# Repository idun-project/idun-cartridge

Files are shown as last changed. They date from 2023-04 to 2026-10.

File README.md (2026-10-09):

## Idun for the Commodore 128 and C64

This is the home of the idun-cartridge for the C128/64. Here you will find the latest software, along with source code, sample applications, and other content.

This innovative cartridge integrates a Raspberry Pi to provide a fast hardware interface, enabling features such as virtual disks, networking, and the ability to run modern applications. Users can interact with the cartridge via BASIC commands, a web-based file browser, or SSH, and the project supports developing new software in 6502 Assembly, Lua, and even C and Z80 Assembly. There's an optional Commodore Kernal patch that allow native software to access cartridge functionality at high speeds, effectively turning the cartridge into a "hard drive" for Commodore.

What does it do? It's easier to show in a demo, and there are many demo videos on [YouTube](https://www.youtube.com/@idunproject).

There's also a [Discord Server](https://discord.gg/qUGaUCaBEU) for the project. This is for idun-project discussion, new user advice, beta testing new features, and general retro-computing banter with a  Commodore bias.

### Hardware

The idun-cartridge uses a Propeller 1 micro-controller to provide a fast hardware interface between the Commodore and a Raspberry Pi ("RPi") that runs a customized Linux OS. The cartridge is designed to work and fit best with the Raspberry Pi Zero 2. However, any recent Raspberry Pi can be made to work.

The first set of photos show the idun-cartridge with RPi Zero 2 fitted. As you can see, a standard-sized C64/128 cartridge case can be hacked to cover the board, but leave the RPi, ports, and button accessible.

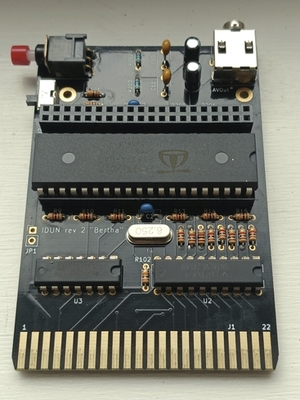
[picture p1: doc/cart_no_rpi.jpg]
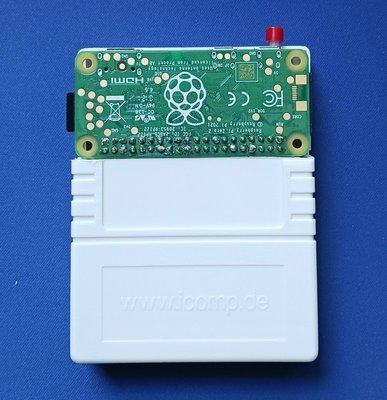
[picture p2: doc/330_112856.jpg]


 A Model B RPi will also fit on an idun-cartridge, as this photo shows. For both Model Zero and Model B, the RPi is fitted on top of the idun-cartridge and upside-down. For the Model B, a case or other support is essential because of the weight.

You can also fit a Model A RPi, but the headers must be relocated to the opposite side of both the idun-cartridge PCB and the RPi itself. In this case, the RPi will be on the bottom (under the idun-cartridge), as shown here connected to a flat C128.

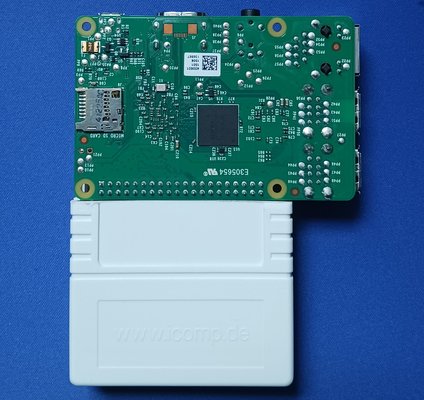
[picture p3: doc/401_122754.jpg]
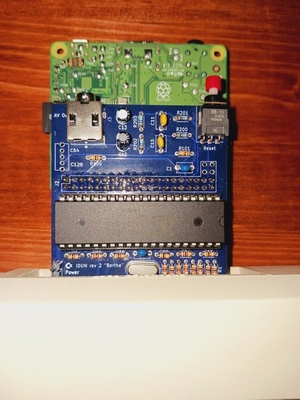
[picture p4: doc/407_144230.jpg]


### Support the project

The best way to support the project is to [buy a hardware kit](https://www.tindie.com/products/29946/) from the online store. The kit comes with everything needed to assemble the idun-cartridge, except for the Raspberry Pi, which you will need to obtain yourself. Only basic soldering skills are needed, since the PCB is strictly through-hole components.

### Quick start

#### Download SD Image

You can download the customized Arch Linux OS image and flash it to a microSD card.

1. Ensure you have a suitable SD card compatible with your Raspberry Pi and at least 4GB (recommend 16 GB).
2. [Download Image](https://drive.google.com/file/d/1j5v-0p9-eopSoVMuX6h2P_U8w21OJF-Q/view?usp=drive_link)
3. Use [Raspberry Pi Imager](https://www.raspberrypi.com/software/) or a similar program to write image to SD card.
4. **IMPORTANT** If you have received an idun-cartridge with a _unique serial number printed on your instruction sheet_, then you need to transfer that serial number onto your SD card. This is essential for your cartridge to work properly. Using a text file editor, modify the file "idunhw.toml" located on the first partition of the SD card. This is the "boot" partition and it is in the FAT32 disk format, which should easily mount on the same computer you used to write the image. Open the "idunhw.toml" file and set the serial number you received in the `hw.serial` line of the file, then save it back to the boot partition.

If you are going to use idun-cartridge on a C64 Ultimate, then you need to install the Ultimate configuration file before trying to use the cartridge. You can grab the file [here](https://raw.githubusercontent.com/idun-project/idun-defaults/refs/heads/main/Idun_c64u_run_first.cfg) and transfer it to your Ultimate by any available means (i.e. network, USB). Then, *run that config file* from the Ultimate menu and *save the new configuration* to Ultimate's Flash.

Your microSD is now ready to use with your idun-cartridge. To expand the file system or setup networking, follow the additional instructions in [setup-rpi.md](https://idun-project.github.io/docs/doc/setup-rpi/).

#### Power

It is recommended that you power the RPi externally from a USB power supply. The jumper (JP1) that allows power to come from the Commodore is not installed by default, and only suited for the RPi Zero 2. Even then, it makes it too easy to turn off the Commodore and Raspberry Pi without first shutting it down via the button. Plus, it is nice to be able to access the cartridge using the web filebrowser, emulation, or `ssh` while the Commodore is switched off.

#### Cartridge Mode & Reset

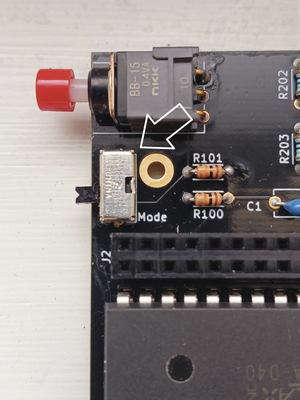
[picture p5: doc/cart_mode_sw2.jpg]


The idun-cartridge has a single "big red button" with dual use. Press and release immediately to Reset everything, including rebooting your Commodore. Press and hold for at least 5 seconds to shutdown your cartridge, which is necessary before powering it down. If you power your cartridge from an external USB power supply, as is recommended, then you will rarely need to perform any shutdown. The cartridge can run for months without requiring any reboot or power-cycle.

As of release v1.2.0, the idun-cartridge has two different modes, controlled by the setting of the Mode toggle switch. When the switch is "Off" (switch position farther from exp. port), the idun-cartridge works on the C128 in its native mode. However, when switched to "Mode", a different software stack is selected as specified by the settings in the configuration file.

With the default configuration file, setting the switch to the "Mode" position enables C64 support. This means that the cartridge can be used on a C64 and that it will boot a C128 into its C64 mode. If you are primarily wanting to play C64 games, then you can most easily do so by launching the arcade.app using the command `go "arcade"`.

#### BASIC commands and launching Apps

When you reset the cartridge by pressing the red button, it starts the Linux shell by default. If you hold down the Commodore key on the C64, then it starts a customized BASIC with some utilities for accessing the Idun virtual disks. The screen lets you use the cursor keys to select which virtual drive to use and on which IEC address; the normal default is `C:`, which is the HOME directory, on IEC device 10. Once you hit "RETURN", you will be in Commodore BASIC.

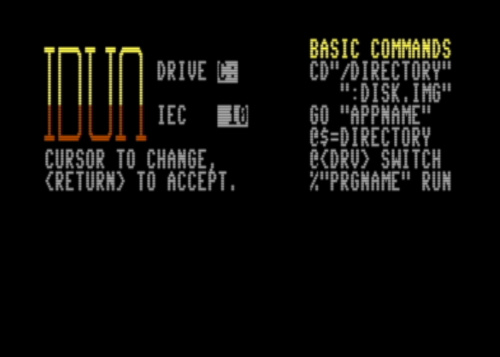
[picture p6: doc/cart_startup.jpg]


From the BASIC prompt, you can use any of the several commands that are briefly described in the boot screen. Mainly, you can navigate the virtual disk by using `@$` (also `F3` on the C128) to load directories, and the `cd` command to change directories. Any disk image file can be mounted by using `cd` and prefixing the image file name with a ":". This will switch you automatically to the `D:` device, which is where the disk is mounted. You can switch back to the `C:` device using the command `@c`, and switch to any other virtual disk this way. If you want to load and run a program, just locate it in the directory, place a `%` in column 1, and "RETURN". This is equivalent to typing `% "prgname"` on a new line.

The other thing you can do is launch an Idun Application. This is done with the `go` command, and entering just that will quickly launch the default shell. The default shell is controlled by the configuration file, and is normally setup to load `dos.app`, which is the idun-shell and an MS-DOS work-a-like. Other applications, such as the Arcade Selector for running games can be started similarly, using `go "arcade"`. Any app on the cartridge can be started this way, and you can create your own using programming tools that run right on the cartridge!

#### Networking and Managing Files

It's well worth connecting your cartridge to your LAN. Convenient file management can be done through the web-based idun-filebrowser at `http://idunpi.local`; it even includes remote file editing and drag&drop. Using the provided `share` command from Linux, you can also enable the cartridge to serve files to your network using both WebDAV and Windows file sharing. Linux terminal access is also there using an `ssh` client from any computer. Then there are also networked applications that allow you to [stream SID tunes](https://youtu.be/EPf45QN3PJk) or [share huge game libraries](https://youtu.be/NZajjJ2tERM) from a Windows computer.

#### Emulating the Cartridge

You can also run [idun-vice](https://github.com/idun-project/idun-vice) to experiment with the idun-cartridge software WITHOUT any actual cartridge; just running everything off of the Raspberry Pi. The emulator is not installed by default, but is easily added with the `apk` packaage management command. It runs Idun software just like on the cartridge and is an excellent way for developers to debug new tools and applications they develop with Idun.

### Configuration

Configuration options are available in `$HOME/.config/idunrc.toml`. There is documentation within that file, but the following hints are also helpful.

1. Because of the "special" VDC hi-res graphic modes used by some of the software (e.g. `showvdc`), it is very important to set the correct amount of VRAM in the configuration file to either 16kB or 64kB, as appropriate. The setting is the second parameter in the `[vdc]` section.
2. Some monitors are picky about how many rows of text they can display in 80 column mode, and how they look when displaying text in interlaced mode. The default is 27 rows, non-interlaced. You can modify this by changing the first parameter in the `[vdc]` section, and for interlaced text, the section `[vdc_interlace]`. Also take a look at the `mode` command for changing the number of text rows on demand (not to be confused with the mode switch described above).
3. If you are using idun-vice to connect to your cartridge from a remote Windows computer, pay attention to enable remote connections by modifying the `io.socket` setting; otherwise, Idun will refuse to talk to remote computers.

### Building Commodore code

The idun-cartridge software in this repository is self-hosting. All of the assembly code is built with the `acme` cross-assembler and everything you need to build and modify it can be done on the cartridge itself. You can perform each of these steps from the Linux prompt:

1. Clone this repository to your idun home directory: `git clone https://github.com/idun-project/idun-cartridge`
2. `cd idun-cartridge && ./setup.sh` -installs additional packages such as bastxt and idun-zcc
3. `cd cbm && make` -builds cartridge software
4. To make the new cartridge software active, just `sudo make install` from the `cbm` directory.

See the [Makefile](https://github.com/idun-project/idun-cartridge/blob/main/cbm/Makefile) for details.

### Patched Commodore Kernal (Optional)

The latest ROM kernal patch can be created easily with idun v1.1.9 and above using the command `mlua makerom.lua` from within the Idun Shell. The patched ROM file(s) will be found in your home directory on the cartridge, and most easily copied using the web file browser or a network command like scp. By default, this creates a two 16kB kernal replacement ROMs for the C128 (U32/U35).
1. To make the 8kB C64 replacement ROM (U4), use `mlua makerom.lua /8`
2. To make the 32kB C128D replacement ROM (U32), use `mlua makerom.lua /32`

The patches to the C128 kernal overwrite the kernal's support for RS-232 devices. This code is frequently unused by native software anyway. If you also update the C64 kernal (U32), then you lose both RS-232 and cassette tape support in C64 mode.

With the kernal patches in place, things work pretty much the same, except that you can access cartridge functionality easily through standard Commodore ROM kernal routines, rather than loading Idun's own kernel into RAM. So, in theory, native Commodore software that is programmed to use kernal routines for file access can "transparently" access files via the cartridge and at "breakneck speed". Think of it as basically a hard drive for the Commodore without having to go through the Idun software drivers in RAM. So now those drivers can just be overwritten by some program.

You really only need to know about two zero-page variables to control the ROM patch - $9b/$9c (155/156). So you can POKE 155, 10, for example, to setup the cartridge as IEC device #10. And, you can POKE 156, 3 to setup the cartridge to use idun's C: device, which is default configured to the Linux home directory. Using other values let's you easily switch to any Idun device mapped as any IEC device. This opens up the cartridge to native software that can use it for virtually anything without requiring RAM drivers. By the way, setting values in $9b/$9c is just what the little booter program the cartridge starts up with does - When you use the cursor keys to modify the IEC and Idun device selection, you are changing these two memory locations. 

### Programming applications

The idun-cartridge works with many legacy applications. Single-file loaders in particular work very well and load instantly in either C128 or C64 mode. But the point is to enhance both the user and programmer experience with applications that integrate into the idun-cartridge. There are currently 3 well-supported ways to create software for the idun-cartridge.

#### 6502 Assembly

Idun includes acme 6502 cross-assembler, which can be used to build both the contents of this repo and your own programs on the idun-cartridge. You should first decide whether to build a Tool or an App.

1. Tools load from the idun-shell using $6D00-$BFFF, have access to the [kernel api](https://idun-project.github.io/docs/doc/apiref/) and the [toolbox](https://idun-project.github.io/docs/doc/toolbox/), and return the user to the idun-shell on exit. They are typically command-line style programs with arguments, but can also take over the screen and run interactively. Many examples can be found in the [cmd](https://github.com/idun-project/idun-cartridge/cbm/cmd/) sub-directory
2. An App is launched by the kernel at startup using $6000-$BFFF, has access to the kernel API, but not the toolbox _unless_ `sys/toolbox.asm` is explicitly included, and return to BASIC, or not at all. They typically take over the machine and reconfigure the hardware as needed. Examples are `shell.app` (the Linux shell) and `arcade.app` (the arcade game selector).

It is certainly possible to use other assemblers besides acme; just requiring that the header files `acehead.asm` and `toolhead.asm` be ported over to your environment.

#### Lua Scripting

The idun software running on the Raspberry Pi embeds a Lua scripting engine. This allows you to create either Tools or Apps in which much, even a majority of the functionality, is implemented in Lua.

Begin by reading [luaref.md](https://idun-project.github.io/docs/doc/luaref/). There is sample Lua App code in [samples](https://github.com/idun-project/idun-cartridge/tree/main/samples), and the [arcade.app](https://github.com/idun-project/idun-cartridge/blon/main/cbm/arcade.app.d/main.lua) is Lua. These can serve as a template for creating your own Lua App.

 _NOTE: There is a forthcoming tool called `mace` that will generate new Lua Apps automatically, including all the boiler-plate needed._

#### C and Z80 Assembly 

You can create programs that run on the Z80! They launch seamlessly from the idun shell, and return to it on exit. These are more akin to Apps than Tools, except for their use of the `zload` command and launching from the idun shell. The programs can be written in both C and Z80asm code, and can be built directly on the idun-cartridge. For more information, browse to the [idun-zcc](https://github.com/idun-project/idun-zcc) repository.

### Trivia

[Idun](https://en.wikipedia.org/wiki/I%C3%B0unn) is the [Norse goddess](https://youtu.be/0IIcDB3noxE?t=308) of youth and [rejuvenation](https://youtu.be/GiXNEf_NOak).

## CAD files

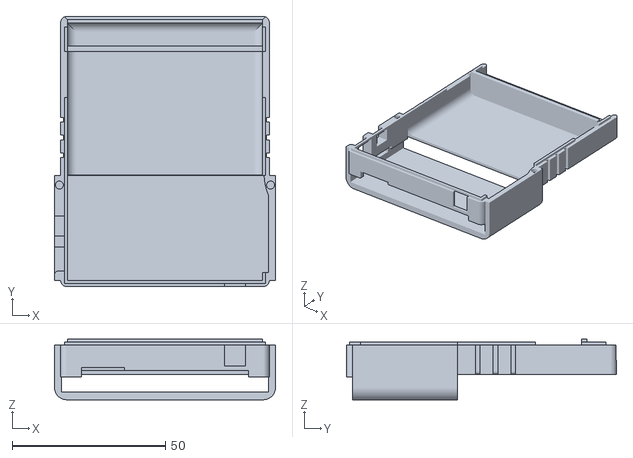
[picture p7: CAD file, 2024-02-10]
hardware/3d-printed-case/case_top.stl
72.0 x 88.0 x 19.7

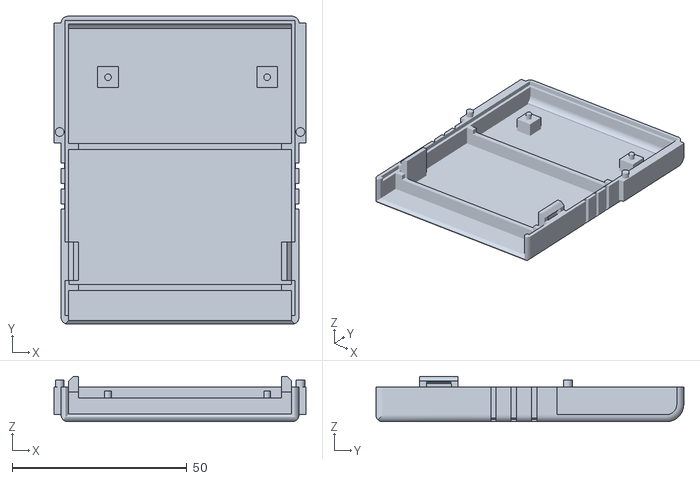
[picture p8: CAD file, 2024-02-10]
hardware/3d-printed-case/case_bottom.stl
72.0 x 87.9 x 13.0

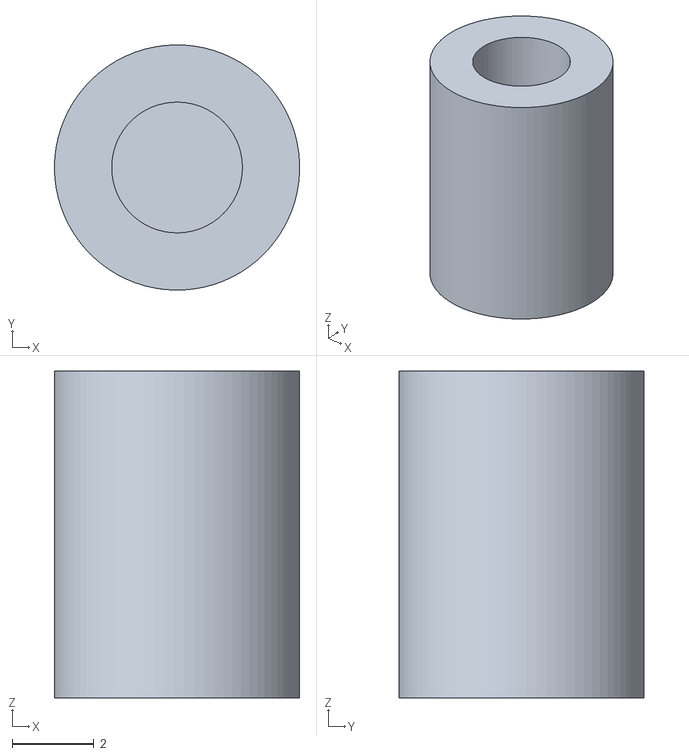
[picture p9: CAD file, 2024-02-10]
hardware/3d-printed-case/reset_button.stl
6.00 x 6.00 x 8.00

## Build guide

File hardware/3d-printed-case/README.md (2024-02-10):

This case design is suitable for 3D printers and was generously contributed by one of our users. This design  is [Licensed under Creative Commons](LICENSE).

There are two main pieces which can be press-fit together; so no screws are required. There's also a replacement button cap that makes the reset button easier to press with the case installed.

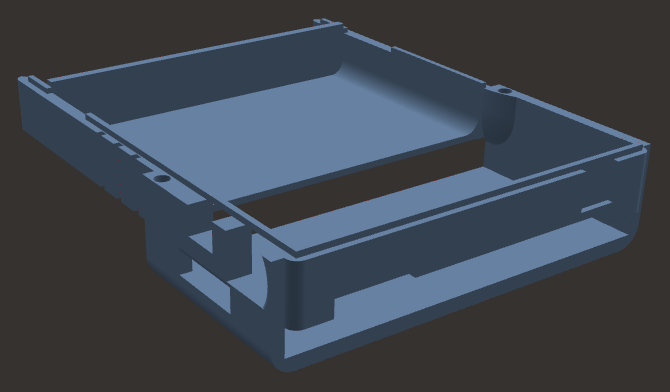
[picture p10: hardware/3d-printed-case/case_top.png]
case top


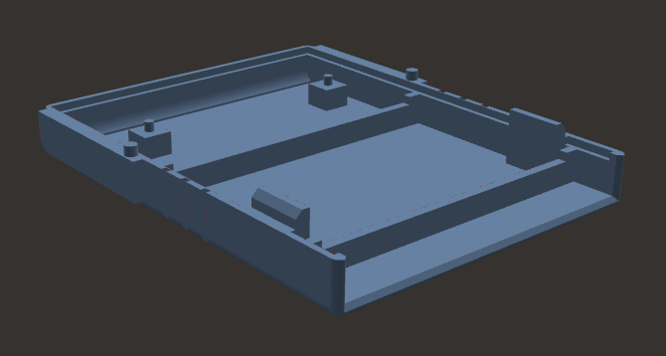
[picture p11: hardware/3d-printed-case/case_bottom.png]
case bottom


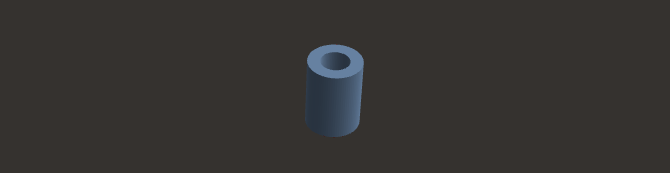
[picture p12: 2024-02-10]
hardware/3d-printed-case/reset_button.png

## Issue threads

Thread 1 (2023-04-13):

Feature Request: configurable shell

paulhocker, 2023-04-13:
First, please don't feel bad about this. I was both excited and sad to see this project. As this is something I was hoping to do for a long time.

I started a project last year called Animal Shell (https://gitlab.com/retro-coder/commodore/animal-shell) which was supposed to be a replacement for the standard command line interface for C128 using ACE, CSDOS and others as inspiration. But nothing as complicated as a operating system. I have actually made some pretty good progress, at least I think so.

You have taken this idea to the next level by incorporating the PI which is also something I had hoped to do so that one day I could use python to run programs on the C64 using the RPI as the interface.

In all, I am very excited to try this out and give my feedback and maybe one day contribute.

I saw by looking at the source code that you have some inspiration from ACE as well. IMHO it would have been great if it had continued.

At any rate, I am mostly here to say that I want to help.

Out of curiosity, how long have you been working on this and have you shared it before? I have seen nothing on this before.

Will be ordering the hardware kit soon.

Paul

idun-project, 2023-04-13:
Hi Paul.

Firstly, thank you for the kind words and support. I also understand the mixed emotions, as I've had similar experiences myself.  This project started in 2020. It was "baking" for quite a while, and even paused most of last year. For better or worse, it is not in my nature to release a project until at least I find it sufficiently useful and complete (like something worthy of calling "v1.0").

I am thrilled that you are thinking about contributing. ACE-128 is largely preserved in the idun kernel - please see [apiref.md](https://github.com/idun-project/idun-cartridge/blob/main/doc/apiref.md). The whole system is easily extended with additional shell "tools" (a.k.a external commands). And, there's certainly room for alternative shells, too.

I wonder if you mind that I'd like to retain this "Issue" as a Feature Request, with your permission. Right now, the shell ("dos.app" is the name of the binary) is hard-coded. It should probably be a configuration variable easily changeable by the user - that way typing "dos" at the BASIC prompt drops you into the shell of your choice. With that option, plus the addition of external commands, the shell can take on differing "personalities", rather than only the MS-DOS inspired "dos.app".

If you agree, let's rename this as "Feature Request: configurable shell".

paulhocker, 2023-04-13:
Of course. Please change the title.

The history of our projects is very similar. I started experimenting in 2020 as well.

I am glad you have decided to share this now, and I can't wait to try it out.

Am I right in saying there are not yet any binary distributions? You need to build everything yourself?

Not a problem, really, just wanted to be sure.

Your work on the VICE emulator is also particularly interesting as not many hardware projects consider it. Great idea.

idun-project, 2023-04-13:
There is a link in the README (see "Quick Start") for downloading an image to copy to microSD and insert into a Raspberry Pi. It has everything needed to run the cartridge.

idun-project, 2023-08-04:
Release v1.1.0 has a configurable shell app for both normal and alternate modes.

Closed 2023-08-04.

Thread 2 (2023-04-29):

Recommended 3D cartridge design

CraigBladow, 2023-04-29:
Thanks for the project.  I've done Propeller based projects and it is a fascinating hardware architecture.  I have the hardware kit and it is progressing towards completion. Can you recommended  or reference the cartridge design you used for 3D printing?

Thanks,
Craig

idun-project, 2023-04-29:
Hi Craig. My own case hacks thus far have been crude, and have not relied on any 3D printing or CAD files. I start with a standard ROM cartridge case, remove what is in the way using a small saw and file, and glue the pieces together. This has been effective for one-offs, but the project _obviously_ would benefit from a better, custom case design.

I'll keep this issue open for further discussion.

Barkfin, 2023-08-27:
This is a magnificent project! Hey I can do a 3d-printed cartridge design, no problem.
I just need some geometry info of the bare board & can whip that together easily.

idun-project, 2023-08-27:
@Barkfin That's great! I'd love to see some better case options become available.

The main PCB is standard C128 cartridge size at 84x57mm. But then the top 28mm is overlapped by a Raspberry Pi Zero 2 that is sandwiched to the main PCB and is just slightly wider. On the pictures you see in the README. you can see I just leave the top portion exposed so that all the ports on the Pi are accessible. Of course, a custom case could have cutouts for ports, and the button and switch on the main PCB. This would nicely enclose everything, but obviously would only accommodate the Pi Zero, and not the larger Model B Pi's, for example. The "open top" version has the benefit of working with more Pi's.

Anyway, I think the summary is that it needs to be a case that fits the Raspberry Pi the user intends to use (RPi Zero 2 is "recommended"), but has an "extension" of 55x57mm for the bottom part of the main PCB, and the proper height dimension to fit in the Commodore cartridge slot opening.

Barkfin, 2023-08-27:
Yes, as I figured, somebody already did this:
https://grabcad.com/library/c64-cartridge-case-1

Anyway this project is completely accessible, have a look at some of the geometry details.
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

idun-project, 2023-08-27:
@Barkfin Yes, that is indeed the "standard" Commodore cartridge dimensions. It will fit the idun-cartridge WITHOUT the Raspberry Pi, as long as the center screw post is removed - there is no hole in the idun-cartridge PCB to accommodate that. So, the necessary modification is hacking off 29mm from the top and (if desired) reforming that area to fit over the Pi nicely.

Barkfin, 2023-08-28:
Whoops, I just realized I had the Pi-2 upside down 😄

So the Pi-2 is actually 30mm x 65mm wide (at least according to the geometrical model I found).
The cartridge model extends 2.45mm past the end of the board, so that implies a 32.5mm cut top the top case.
The Pi-2 standoffs are what, about 8mm tall?

If I just do a simple trim to the top case (plus eliminate the center post) then we get this:
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
(Anybody who cares to try, here are the STEP-214 files)
[Idun cartridge case.zip](https://github.com/idun-project/idun-cartridge/files/12450316/Idun.cartridge.case.zip)

idun-project, 2024-02-10:
There's a new and improved 3D case design, generously contributed to the project by @_.cygnus._ . If you want a case, then checkout the design files in the GitHub repo:

https://github.com/idun-project/idun-cartridge/tree/main/hardware/3d-printed-case

Closed 2024-02-10.

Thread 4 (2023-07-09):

Boot issues on Neo128 board with Saruman SRAM

insanity213, 2023-07-09:
The RasPi boots to arch (watching via HDMI) but I crash to the monitor when the Neo128 fires up. On initial boot it always dumps at A803B with processor state SR:31 AC:04 XR:03 YR:00 SP:F5. If I reset with the Idun’s cart button it’ll crash to the monitor at seemingly random vectors or sometimes just hangs. Disassembling memory in these areas doesn’t seem to yield anything significant, seems to just be random junk in there but admittedly I’m not the brighest when it comes to 6502 assembly. The only noteworthy difference I can think of is that I’m using the Saruman SRAM module on this Neo build.

Some things I’ve tried so far:
Powering the PiZero2 either internally or externally
Wrote a new micro SD card with the latest image
Tried the original CBM kernal and JiffyDOS
40 or 80 column mode
Reflowed IC solder joints
Retested on original C128 board with DRAM and the cart functions perfectly

I did successfully boot one time but as soon as I issued the DOS command it crashed to the monitor.
I’m starting to wonder if this could possibly be a RAM timing issue with the static ram replacement module I’m using instead of DRAM? I was wondering if you’ve used this cart with a SRAM replacement or ran into any tight timing issues when developing the cart.

Monitor output of A8007 and A8017 looks correct.

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

idun-project, 2023-07-09:
From the monitor, it would also be useful to see the contents of $C1:
M C1 -> should be "00 13".

If that is Ok, then the next thing to look at is the disassembly at $1300.
D 1300 -> first instruction should be JMP $1305, followed by lots of valid 6502 code starting from $1305.

If this is no good, then the issue is on the I/O side, for sure, and not on the ROM side, of the cartridge functionality. Naturally, the timing is critical for reading the I/O at the cartridge port. It's not yet registering with me how the SRAM mod could effect the bus timing when reading from external I/O at $DE00. It would have to be effecting something fundamental with the C128 Phi2 clock OR with the "clock stretching" that it does when running in 2MHz mode.

insanity213, 2023-07-10:
I tried 40 column mode.  It seems the Idun is more likely to boot on a cold start in 40 column mode but crashes within a few minutes.  I was actually able to enter DOS then hit F7 to get to the Linux shell on one occassion.

After crashing back to the monitor I looked at the output of $C1 and $1300.  C1 was 00 00.  $1300 looks different each time I've rebooted/crashed/dumped the RAM in the monitor.  Also had one crash where it just hung on a garbled screen.
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

Anecdotal / mostly unrelated - In the past on the C64 I had problems with combinations of SRAM/Cartridge/Kawari VIC-II that I was able to work around by 'tuning' PHI2 a bit.  I disconnected PHI2's output from the CPU and generated my own PHI2 through a pair of inverter gates on an LS14 and manipulated it a bit with a low value capacitor in order to get the system stable.   I didn't have any of these problems in machines with DRAM.  The Kawari developer also made some tweaks to RAM timing to get his device to work with SRAM but I'm not 100% sure exactly what he did.  I think it had something to do with RAS/CAS.

I know the 8502 in the 128 doesn't generate the PHI2 and I'm comparing apples to hand grenades but I though it was worth mentioning.  I'm wondering if CAS or RAS falls at a different rate when attached to an SRAM module and it nudges the timings off the mark just a hair, similar to the Kawari issue. Playing with the edge of PHI2 may help those timings hit the mark?  All guesses on my part really...  I wish I had a logic analyzer to dig in deeper, but I only have a cheap 2 channel scope.

idun-project, 2023-07-10:
The plot thickens. If the system goes from crashing immediately, to working but unreliabe, just by switching to 40 column / 1 MHz mode, then it makes sense to assume that Phi2 pulses are affected by the SRAM. And that is causing the cartridge IO to fail outright in 2 MHz mode and to become unreliable in 1 MHz mode.

Anything 100% reproducible that leads to a crash in 40 column mode could help localize the problem. I think 80 column mode will remain "hopelessly" broken until the root cause is better diagnosed. Any O-scope output of Phi2 at the cartridge port on a DRAM vs. SRAM C128 would also be useful.

I have to say the timing tolerances are quite tight already. If the Phi2 edge pulses are coming quicker than normal, we can't just patch the cartridge software to allow for that - spare cycles aren't available here and the Phi2 clock is what is used to "trigger stuff" in the code.

insanity213, 2023-07-18:
Problem resolved, it was related to the 1mhz clock line between the VIC-IIe and the cartridge port.  Also noteworthy was that with DRAM installed the system was marginally more stable but still had issues.  At least I was able to boot into the Idun DOS shell and run a demo or two before it would crash.  With SRAM I was lucky to get it to boot at all.  My issue seems to stem from the amplitude of the 1 mhz clock generated by this particular VIC.  I swapped it out for a spare and the system started running perfectly.  I guess some VICs have stronger clock signals than others.  See attached scope pics.

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

insanity213, 2023-07-21:
Yeah, kind of a weird one.  I guess having just a tiny bit less amplitude on that signal was enough to make the falling edge too short for stuff to time right.  I had some odd behavior with the Ultimate II cart as well with that weak VIC in there.

I did try putting a 330 in parallel with the 1k on that line and it didn’t make a difference.  I didn’t want to go too much lower and let the smoke out of the Propeller though.  Thanks for your help, I really appreciate it!

Ray

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

idun-project, 2023-08-14:
@insanity213 I was wrong in my initial assumption that the read response time for the cartridge couldn't be improved (Propeller multi-core for the win...)

In light of the resolution to #5 , it might be worth testing again with your original VIC-IIe chip.

insanity213, 2023-08-15:
I reflashed my SD card from scratch with 1.1.1 and reinstalled my 'weak' VIC-IIe.  Your fix certainly improved the situation but the machine is still quirky with this VIC and the Idun cart.  I ran the cube app for about 15 minutes then started to see corruption in the video.  Upon exiting the cube app and going back to the shell I got some strange behavior with screen updates and cursor movements but the machine didn't full out crash like it used to.  I tried to reset with the button but struggled to get back to the shell.  Also, there may be another unrelated bug at play where for some reason 1.1.1 is ignoring the VDC config in idunrc.toml.  I'll open a separate issue for that.

Closed 2023-07-18.

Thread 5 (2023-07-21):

IDUN Not Loading on C128D(CR)

kd4cbm, 2023-07-21:
It appears as though I either have an issue somewhere or the internal drive may be causing issues with IDUN loading on a C128DCR.

RPi software wise, the OS and everything else on the SD card is bone stock with zero modifications with the exception of installing the Vice package.

Has anyone had a successful load on that specific 128 type? RPi Vice appears to be working locally, albeit a bit slow.

The cart does hold up the c128 boot process until the Pi completes loading so I assume the correct lines are toggling.
I did do another SD card where I incremented the device ID's by 1 in the config file. The result was the same though.

I have a 128 flat I might be able to test with, I'll just have to figure out where I hid its power supply.

idun-project, 2023-07-21:
Hi. Much of the idun-cartridge testing was done on a 128D. I don't have a working 128D(CR) to test with right now, but can't foresee why there would be any issue. Internal floppy (is it set to IEC device #8 or #9?) should not effect boot process.

Are your symptoms anything like those reported in issue #4 ?

kd4cbm, 2023-07-21:
I've had very, very, few break conditions. What I'm seeing is either the machine boots to a ready prompt or just hangs at the Commodore copyright notice that shows just before ready does.

I've looked at issue #4 and plan on probing around with the scope over the weekend to see what I can find.

The internal drive is still set to 8. If it works on a D, I would imagine the CR variant should work as well.

I'll post back here once I start probing around and have some useful info to share.

Thanks!

kd4cbm, 2023-08-01:
Sorry for the delay on the follow up. I wanted to rule out any hardware issues before I started probing and USPS is getting slower and slower these days.

I believe I am in fact seeing the same issue as described in issue #4, they are just presenting themselves a little differently. Differently as in the 128s are either hanging while attempting to load the cartridge data into memory, or just booting normally with no code loaded. The behavior is the same between the machines.

On the scope, there is a pretty good amount of slew and noise on the clock line which may explain why the user who reported #4 got better results with a stronger VIC. That extra .4v may have been enough to get the timings in check. I tried dropping the clock line resistor down slightly to 800ohms with no improvement. I'm a little cautious on going too low, since I've already smoked one Propeller due to my ham-fisted Pi alignment.

I did try the VIC from my flat 128, but the results are the same regardless of the VIC, or which machine it's in. I'm not terribly surprised by this though since both VICs were manufactured within 2 weeks of each other, and their clock outputs are nearly identical to each other in terms of output. If I can get my hands on an expansion port breakout, I'd like to try intercepting the clock output at the port and buffering it with another 74LVC245 or similar directly to the MCU pin to see if it solves anything.  Or even just jumpering from a point somewhere close to the VIC directly to the input resistor on the cart...

idun-project, 2023-08-01:
Hi. So if you have a chance later, would you please provide the date codes on the two VIC-IIe chips you have? I'd like to compare with those in my test machines, and also find a VIC-IIe of my own with which I can reproduce the problem.

kd4cbm, 2023-08-01:
4585 and 4385 are the date codes on the 2 VIC-II's I've got in hand. I'd be happy to loan you my spare if it would be helpful, especially if it leads to a solution. My C128 use case makes this particular cartridge perfect for my needs once I get things up and running.

I would prefer to facilitate that communication via e-mail if you're interested. Google's e-mail service, same username

idun-project, 2023-08-14:
Thanks to @kd4cbm for lending me one of his R5 VIC-IIe's. The following was learned:
1. The 8564R5 is unreliable with the idun-cart.
2.  Phi2 as detected at the Propeller input is identical for R5 and R6. It does not appear to be a clock problem.
3. The difference is thermal. My flat C128 booted Idun perfectly the first time with the R5 chip, and anytime that I allowed the C128 to cool completely back to ambient temperature. It becomes unstable after a short warm up time, which affects the timing tolerance for reading from the cartridge port.

Release v1.1.1 shaves 80ns of response time for cartridge reads. This is enough for it to work reliably with the R5 chip.

Closed 2023-08-14.

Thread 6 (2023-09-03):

Out of sync 80 column mode

celso, 2023-09-03:
Hi,

First of all congrats on the idun cartridge project, I just finished soldering mine, had it running in my C128DCR and it's mindblowing. Thank you.

I'm having problems running DOS in 80-column VDC mode with my C+1084S monitor (connected with the std analog RGB cable).

It boots fine at first, shows the IDUN banner, but as soon as I type and run DOS the video gets out of sync. See attached screenshots.

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

I can see DOS is running properly though, I can even type commands and it's fine, just doesn't show stabilized video.

I looked into idunrc.toml for options. And found:

```
[vdc]
offset = 169
config = [27, 16]       # VDC default lines, memory size in KB
```

Changed it ,64 since afaik the DCR has 64K VRAM, but it didn't help.

Any clues on what might be happening and how to fix it?

celso, 2023-09-03:
I did try setting an interlaced mode and got good video:

```
mode vdc 0 80 47
```

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

Still, I tried a bunch of non-interlaced modes changing the number of lines from 20-27, and they were all out-of-sync.

celso, 2023-09-03:
On a separate note idun doesn't seem to be picking the `/home/idun/.config/idunrc.toml configuration` at all. I changed a few settings, then resetted the cartridge, even rebooted the raspberry pi, just in case, and nothing.

Is this the correct path? Do you want me to create a new issue for this?

idun-project, 2023-09-03:
Hi. I would suspect that the monitor was having trouble syncing with the default 27-line non-interlaced text display. Changing the default lines to 24 in the configuration file should work. But typing "mode vdc 0 80 24" at the C: prompt should also work.

On my CRT I can set the number of lines up to 29 non-interlaced and 50 in interlaced mode without sync issues- just at very high line counts it does start to disappear off the top and bottom of the CRT.

Have you also checked the PAL/NTSC configuration setting is correct for your C128?

idun-project, 2023-09-03:
On the idunrc.toml question, please do open a separate issue to describe exactly what you are seeing.

celso, 2023-09-03:
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

Changing to lines 24 lines didn't work either, video stays out-of-sync. It's weird because I get good video before I run the DOS command.

All the interlace modes work though.

My machine is PAL for sure. I did change the video>config to 0 (NTSC) just in case, and it didn't work either.

celso, 2023-09-03:
> On the idunrc.toml question, please do open a separate issue to describe exactly what you are seeing.

I found the issue. `idumm` is picking `/home/idun/idun-sys/idunrc.toml`, not `/home/idun/.config/idunrc.toml` like I assumed (because there a file there too).

idun-project, 2023-09-03:
> I found the issue. `idumm` is picking `/home/idun/idun-sys/idunrc.toml`, not `/home/idun/.config/idunrc.toml` like I assumed (because there's a file there too).

Hmmm. Could there be a syntax error in your .config/idunrc.toml file? IF so (or if it does not exist), then the cartridge will revert to using idun-sys/idunrc.toml.

Something to try: Just copy idun-sys/idunrc.toml to ~/.config. Then, edit the .config one, reset the cartridge, and see if the setting is changed.

idun-project, 2023-09-03:
Also, I will try to recreate what you are seeing using an Amiga 1080 monitor (it's similar to the 1084S). I feel like maybe the vertical sync timing could be off, and your monitor isn't liking where the top of the display starts in the dos shell.

celso, 2023-09-03:
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

That was it. It's now picking the config in ~/.config. Thanks.

celso, 2023-09-03:
> Also, I will try to recreate what you are seeing using an Amiga 1080 monitor (it's similar to the 1084S). I feel like maybe the vertical sync timing could be off, and your monitor isn't liking where the top of the display starts in the dos shell.

Thanks. Let me know if you want me to run some tests.

idun-project, 2023-09-03:
Everything looks perfect on my 1080 monitor.

Does the 1084S have a "Vertical Height" adjustment pot on the back? If so, I'd try giving it a tweak, if you have not already. Also, I assume you've already tried all the front panel adjustment pots, and so those are definitely not an issue.

idun-project, 2023-09-03:
Another test: In the dos shell, type "mode debug vdc 1", then use the cursor keys to see if the graphical display comes into sync.

celso, 2023-09-03:
> Everything looks perfect on my 1080 monitor.
>
> Does the 1084S have a "Vertical Height" adjustment pot on the back? If so, I'd try giving it a tweak, if you have not already. Also, I assume you've already tried all the front panel adjustment pots, and so those are definitely not an issue.

Yeah I played with all the vid adjustment pots in the monitor, including the vertical height one in the back, didn't have any effect on the sync issue.

celso, 2023-09-03:
> Another test: In the dos shell, type "mode debug vdc 1", then use the cursor keys to see if the graphical display comes into sync.

The graphical modes do show good video, see attached pic. The issue seems to be related with the non-interlaced text mode.

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

celso, 2023-09-03:
Aditional information: `mode debug vdc 3` works too. All the others 2, 4, 5, 6, 7 are out of sync in my monitor.

idun-project, 2023-09-03:
Are you willing and able to re-build the source for this repo? (using acme assembler, and you can do it right on the cartridge!)

We could experiment with tweaking the settings located here: https://github.com/idun-project/idun-cartridge/blob/fda7e2bbea1d74ec53b5439baa0757f230e4b9a6/cbm/sys/acevdc.asm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

celso, 2023-09-05:
Quick update. I changed the VDC register $00 (Total (Clock cycles per rasterline - 1)) from 126 to 128 (because I read somewhere that 128 CCLKs per line was the correct value for PAL machines) and I got a perfect stable video. It looks good. I'll try to learn more about the VDC timings and will do more testing later this week.

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

idun-project, 2023-09-05:
Fantastic!

I will also do some experimenting with that value and we can decide together whether to make a patch.

Best,
Brian

idun-project, 2023-09-16:
@celso The pull request I have been testing is slightly different than your change... it sets R0 to 127 and also modifies R4 and R7, as you can see in the diff.

Can you try this fix out on your system?

celso, 2023-09-18:
I would, but now, for some reason,  idunmm started crashing on me and I can't quite understand why. Do you have any clues?
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
idun-project, 2023-09-18:
Are you on v1.1.2?

It could be a configuration file problem. Is it possible that both .config/idunrc.toml and idun-sys/idunrc.toml are both modified? A fix t try would be copying unmodified idun-sys/ config file over the .config/ one, then customizing whatever you need changed in .config/.

celso, 2023-09-18:
I thought about that and tried it, didn't solve the issue. I went through some arch package updates before, maybe I upgraded one of the libs that idunio links again't and triggered this problem. Can you check the source line numbers in the trace I sent here and provide more context on what idunio is trying to do? I don't think you released the sources for these binaries did you?

One other option is to burn the image again and start from scratch.

Nore sure about the version I have is, or how to check it, but I downloaded the sd card image ~2w ago. sha256sums are:

1e0ea720f50ffc179cd3635680db6b53390ef490ff506220d81be8e181d7c7e4  /home/idun/idun-sys/idunio
fa1b9e27f5b174e21e6a61e08aa6347da8090e90f228b72daa72810c4f6812b3  /usr/bin/idunmm

celso, 2023-09-18:
Nevermind, as I wrote the last msg, I thought about running idunio trough strace, and found the issue:

`openat(AT_FDCWD, "/dev/uinput", O_WRONLY|O_NONBLOCK) = -1 EACCES (Permission denied)`

Turns out that some package I installed change the /dev/uinput permissions to 0600. Changed them to 0666 and the issue went away, all working now. I'll try your PR later today.

celso, 2023-09-19:
@idun-project I tried your vdc_pal branch settings and it works well, picture is stable. I think you can merge.

mvcube, 2025-08-17:
I've just filed a new issue (#27) because the problem doesn't seem to be solved for me. I'm on the most recent version.

Closed 2023-09-21.

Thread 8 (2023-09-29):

Upstream raspberrypi software changes break cartridge

idun-project, 2023-09-29:
At the time of this writing, there are upstream changes to the raspberrypi Linux software that makes the serial device (/dev/ttyAMA0) inaccessible to the `idun` user, because of the permissions on the filesystem node. This prevents the idun-cart from booting. The changes would be installed if a full system upgrade is done using `pacman` (i.e. `sudo pacman -Su`).

As a workaround, DO NOT do a full update until there is a resolution to this issue. If you MUST install some packages, you can do so with `sudo pacman -Sy package-to-install`.

idun-project, 2023-11-09:
Fixed!

The upstream release attempt to create a console on the serial port using systemd. This has to be disabled using the command:

`sudo systemctl mask serial-getty@ttyAMA0.service`

Furthermore, the permissions for `dev/ttyAMA0` must also be changed to ensure there is group `rw` access to the serial port.

`sudo chmod 660 /dev/ttyAMA0`

Once these two commands are done, the idun-cart should work fine with the latest versions of Arch Linux.

The standard sd image has been updated now to include both latest Linux software and this fix.

Closed 2023-11-09.

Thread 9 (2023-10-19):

Pi/idun cart not booting

anovaprint, 2023-10-19:
Struggling to boot into my idun cartridge and hoping for some assistance. My main questions are what order I should be setting this up in and what I should expect when booting. Also, this is the first board I've assembled on my own so I'm leaning hard towards some type of user error here. I'll try to include pictures in case I've done something horribly wrong (I've got some flux remover in the mail to clean it up a bit better)

I'm using the supplied SD card and the original pi zero w which I understand will want to be powered independently. However I simply get a series of blinking lights on the pi and I never see anything come up on screen. I also tried booting the pi separately without anything attached and get the same result. It ends up with seven blinking lights which is supposedly "kernel not found" but I couldn't tell you if that is accurate or not. Hitting the reset button seems to have no effect

I'm especially curious in what order I should be powering things on. I assume once everything is assembled and inside the 128 I would want to power on the pi first and then power up the 128. I assume I would want to give it a couple of minutes to boot and eventually I would see something on screen on my 128. Does that sound correct? Should I be able to boot the pi independently without anything attached and verify it is at least booting properly?

Also had a bit of a follow-up question on what those partitions should look like on the SD card. Is there anything extra I might need to there?

I'm probably missing something very silly and appreciate any assistance on what I might be doing wrong here and how I can get going on this project.

Much thanks
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

idun-project, 2023-10-19:
Hi. I think the problem is that you are using a Pi Zero W, which is not supported with the latest Linux image. The issues is that the image is for an ARMv7 device, and the original Pi Zero is ARMv6. This will certainly prevent the RPi from booting, as the kernel image is just not compatible.

If you do not have access to another Raspberry Pi, then we can try using an older image for the RPi Zero W. You'll need to download the image from this link and flash it to the SD card using the Raspberry Pi Imager app, or similar: [idunpi_armv6.7z](https://drive.google.com/file/d/1-f4fZqi1PGydYXPUaHLZCb5UNGgmPkZW/view?usp=sharing)

If the above image boots your RPi successfully, then just give it about 10-15 seconds to fully boot, then turn on your Commodore. The Commodore will then show the Idun boot screen, if the cart is working properly.

There may be a path forward for using the original RPi Zero, but only for awhile. The reason I was forced to drop support for it is that upstream Linux providers are dropping it because the Raspberry Pi Foundation has announced it is end-of-life, I believe in 2024. Obviously, they are anxious to move users to the RPi Zero 2.

anovaprint, 2023-10-20:
Hey, I think that's it! I really appreciate you walking a first time user through it all.

I have a couple of pi 4s that are locked down on other projects so using the older armv6 image at least tells me the cartridgeassembly seems to have gone as intended.

This will be a good excuse to order the new zero 2 w so I can continue to keep up with the project.

Thank you so much for the help!

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

anovaprint, 2023-10-20:
I'll let you know if I have any issues with the new pi but I expect it will go smoothly

idun-project, 2023-10-20:
Happy to help and glad to see that was the problem.

The Pi Zero 2 is a worthwhile upgrade and seems to be the same price; so I guess that is why they are retiring the original Pi Zero.

Closed 2023-10-20.

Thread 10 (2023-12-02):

Idun Cartridge Testing Results for 2B and 4B

paulhocker, 2023-12-02:
I FINALLY got around to building my board. No issues with the build, although I was curious if the "arcade" switch was supposed to come with the kit or if I was supposed to get that myself. Not a big deal, actually.

At any rate, I did not have a Pi Zero 2 (on order, short supply) so I used a Model 4B I had spare, and a Model 2B as well. I do have a model 3B+ I will try as well.

At any rate, I had zero issues with the 2B, but the model 4 gave me all kinds of trouble. I have included 2 video links for you to view.

The first link, is me running with the Model 2B, pretty boring but of interest is that I continually kept using the C128 reset button expecting it to boot to idun. Is it supposed to, or will that only happen when using the reset button on the CART?

https://youtu.be/jbOK3jEa3vY

The next link is me using the 4B. The video shows a couple of times where running hello.app actually crashed the cartridge, and then something weird near the end I reset the cartridge and it loaded the arcade.app. I had to shutdown and reboot the cartridge to return to regular mode.

https://youtu.be/ft0YlNeRaXc

Anyway, it is not all bad, and I hope to do some more testing over the holidays.

This is a very exciting project.

paulhocker, 2023-12-02:
I found the docs in the base repo that state most apps can be exited using the run/stop key or pressing the c= + back arrow

neither of these work for me

using run/stop on any pi results in a crash -- c= + back arrow does nothing as well

I am testing using the hello.app

idun-project, 2023-12-02:
Hi Paul. Thanks for all the feedback. A few quick thoughts before diving in deeper on any of the issues you are seeing:

- The C128's built-in reset button will not reset the cartridge. If you are in the idun shell, then it will return you to BASIC with a fully reset machine and the cartridge "invisible". This is the same as typing the "exit" command in the shell. The "big red button"  resets the cart+C128.
- I run my test machines with JiffyDOS enabled. It's not a problem.
- I'm **curious to know if you have the latest** v1.1.3 idun software installed.
- Try holding down "STOP" for a second or two to exit the .app sample programs.
- My own testing with the RPi 4 has been very limited so far. I've done a little bit with a 4B many months ago. I'm currently waiting on a Compute Module 4 with an adapter to test more vigorously, with an eye toward eventually releasing 64-bit (ARMv8) versions alongside the ARMv7 I'm doing now.

idun-project, 2023-12-02:
I see I shipped your kit back in mid-April. The little switch for the arcade mode was not included at that time because the feature came a few months later. The new kits have this part: https://www.digikey.com/en/products/detail/te-connectivity-alcoswitch-switches/1825232-1/4021554

The most mysterious of your issues is that you obviously invoked arcade mode without the switch and without modifying your idunrc configuration file. This was with the Pi 4B? It smacks of an electrical contact being made on the PCB where the switch is normally installed... acting as a "ghost switch". Something to be on the look out for if you don't install a switch.

idun-project, 2023-12-04:
Hi. I put in a fix for the hello.app freezing. It is commit aec4dd6. If you want to try the new binary, it is in idun-base/apps too.

I think we can close this issue. Thanks for the feedback.

Closed 2023-12-17.

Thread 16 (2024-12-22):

Enhancements to the `mount` command

idun-project, 2024-12-22:
The current version of `mount` only allows mounting of virtual floppies with the option to assign it to one of the drives already configured for this type of device. The enhanced version will be expanded as follows.

1. Add the ability to mount a virtual directory from the Linux filesystem to any unused device or any device currently used as a virtual directory or virtual floppy.
ex. `mount /g /8 /home/idun/OneDrive/Games` - This would change the G: device to map IEC device 8 and point to the specified path.
2. The mount command changes will persist across reboots. Currently, the command does not change the actual configuration, so a reboot puts everything back to whatever is currently in the config file. The enhanced command will make changes to the configuration and persist them in `~/.config/idunrc.toml`.
3. Additionally, the boot device selection screen needs to reflect the correct IEC device addr from the config file.

idun-project, 2025-03-22:
This can probably be accomplished by adding a "path" attribute for VirtualFloppy entries in the config, and making the "devices" array of the config editable at run-time. Then, both "path" and "addr" attributes can be changed by the `mount` command and preserved across reboots. The combination of `toml` & `toml_edit` crates may handle all the toml parsing & formatting.

*v1.2.1*

idun-project, 2025-04-19:
Final solution was to split this off into 2 idun-shell commands: `mount` and `assign`.

`mount` works the same as before for disk images, except now the mounted drives survive reboots and power-cycles.

`assign` works similar to mount but assigns a directory on the RPi to an idun drive. These assignments also survive across reboots and power-cycles.

Both commands only work for drives that are already set to the correct "type" in the config file. So "type=4" for virtual drives used with `assign` and "type=7" for virtual floppies used with `mount`.

I punted on specifying the IEC address on the command line for these commands, If you want to change IEC address, then you do so in the config file.

_v1.2.1_

Closed 2025-04-29.

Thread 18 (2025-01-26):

Add CMD/Jiffy compatible commands

idun-project, 2025-01-26:
It would be nice to have CMD/Jiffy style commands for IEC connected devices in both BASIC and in Idun Dos.

The following commands should work in BASIC and Idun Dos:

- @$  (only in BASIC)
- @#n  (only in BASIC)
- @S:FILENAME  (only in BASIC)
- @N:MYDISK,ID
- @CD:SUBDIR
- @MK:NEWDIR
- @RM:SUBDIR
- @INFO
- @HD
- @CHKDSK:PARTITION

To use the commands in Idun Dos, you have to first `cd` to a device that is mapped to an actual IEC device (i.e. `cd f:`, where the f: device is a device supporting the above commands).

idun-project, 2025-03-25:
First attempt at this is to add the ability to the hook driver so that you can issue commands to an IEC device easily at the BASIC prompt. After doing the command `@#8`, for example, any following commands that begin with '@' will direct to IEC device 8 and the output returned from the device will be displayed. To disable, you can do `@#0`.

*v1.2.0*

idun-project, 2025-04-21:
The final part is to allow "@" commands from the idun-shell prompt. It works by first selecting a native IEC device, probably "a:" or "b:", then you just type the "@" symbol followed by the exact command you want to send to the IEC device's channel #15. The response from the device is reported in the shell.

v1.2.1

Closed 2025-04-29.

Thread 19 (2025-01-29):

Impossible to exit from the `mode debug 7` command

idun-project, 2025-01-29:
Normally, pressing STOP exits from `mode debug`. But it does not work with mode 7.

That seems related to the writing of the "mode.debug" file to the Z: device during the exit procedure. The file write is producing an error and several warnings in the log and itooks like EOT is not properly detected.

idun-project, 2025-03-22:
*v1.2.0*

Closed 2025-03-28.

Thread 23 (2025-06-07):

C64 Reset Issue

idun-project, 2025-06-07:
Two separate users have reported a problem using the cart on a C64 where the main symptom is the cart does not present the boot screen, but it does show a loss of 8KiB of BASIC RAM. This indicates enough variation between individual C64's (or motherboard revisions) that the current manner in which RESET works probably needs modification.

So far, all C128 machines work fine in C64 mode. This is a farther indication that the issue relates to the type of RESET circuit used in the particular C64.

_v1.2.2_

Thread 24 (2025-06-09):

NMI port not working on C128

idun-project, 2025-06-09:
As reported by a user, the first indication was Z80 programs would not launch and run on the C128.

Easiest ways to reproduce are to go into the idun-shell and then use Linux from a remote terminal to try to run commands using `idunsh`. It will emit errors in the log stating "i2c write failed". However, it works correctly for C64.

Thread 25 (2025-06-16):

Directory command not working for IEC device in idun-shell

idun-project, 2025-06-16:
This appears to be a bug that was introduced by the change in v1.2.1 to add support for "@" commands to the idun-shell. Reproduced on C128D with built-in floppy; just shows an empty directory for the floppy with the name "tty", which is also not the correct disk name.

Closed 2025-06-17.

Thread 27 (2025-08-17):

VDC on PAL machine: Display is unstable

mvcube, 2025-08-17:
My Panasonic TV (LCD, 720p, connected to Scart via a simple passive D/A converter) has problems producing a stable image in 80 column mode when in the IDUN shell or any of the dependent environments like Linux or CPem. The screen seems to lose sync for a split second every few seconds. I assume that the VDC timing is not quite correct for PAL machines.

In BASIC, 80 column mode has no issues whatsoever.

idun-project, 2025-08-19:
I don't know the cause of the flicker, but would focus first on your RGB->SCART converter thing, since that is unfamiliar. Where could I find the one you have?

We can also test with graphics modes to see if any of them work without flickering. From the idun-shell:
```
c:> mode debug vdc 1 #displays graphical output; press STOP key to exi#28
c:> mode debug vdc 3
c:> mode debug vdc 5
```
IF you have 64KiB of VDC RAM, then you can also test interlaced modes 2,4,6,and 7.

You can test out interlaced text mode (works with 16KiB VRAM) using `mode vdc 0 80 45` to set the VDC display to 45 lines.

THEN, we can maybe check if other VDC programs are working without the flicker. Launch them from BASIC like so:

1. RESET cart
2. cd "idun-base/games" #change to games dir
3. cd ":games.d71" #mount the disk image
4. F3 to show directory
5. Scroll up and place a "%" in column 1 of "hearts" or "invaders", and press RETURN.

Neither of those games does any thing special with the VDC sync settings.

mvcube, 2025-08-24:
Here is some more info:

I've been using "glitch" and "flicker" interchangeably for a single phenomenon: the momentary loss of horizontal sync, most probably for just a single frame. This only occurs on my Panasonic flatscreen TV (on older 720p model with SCART and HDMI inputs). The Mitsubishi has no problems with the timing in text mode. All the other problems, notably the garbage display in interlace mode, occur on either screen.

I've created a small BASIC program that dumps the default VDC registers to a file. Here is the contents in PC readable form:

[VDC.ods](https://github.com/user-attachments/files/21958606/VDC.ods)

I'm pretty sure that the idun kernel writes different values to the VDC registers than what the C128 kernal does, which, in turn, is causing the display problems. This is my main concern.

mvcube, 2025-08-28:
Never mind: The option -y in pacman did the trick. Suggestion: Update the setup.sh script to include the option.

SUCCESS: The glitches seem to be gone in non interlace text mode.

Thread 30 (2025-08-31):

`copy` command is truncating files rather than fully copying the data

idun-project, 2025-08-31:
Looking into it deeper. I think the recent change to make the "@" commands work with IEC devices in the Idun shell probably messed up the sending of IEC commands from the `copy` and `del` commands. Should probably be a hot fix.

idun-project, 2025-09-10:
The original issue is fixed, but there are some caveats.

1. `copy` does not support the source being a P64 file.
2. The maximum file size that can be copied to a floppy from a virtual drive is 64KiB.

_v1.2.1-4_

Closed 2025-09-10.

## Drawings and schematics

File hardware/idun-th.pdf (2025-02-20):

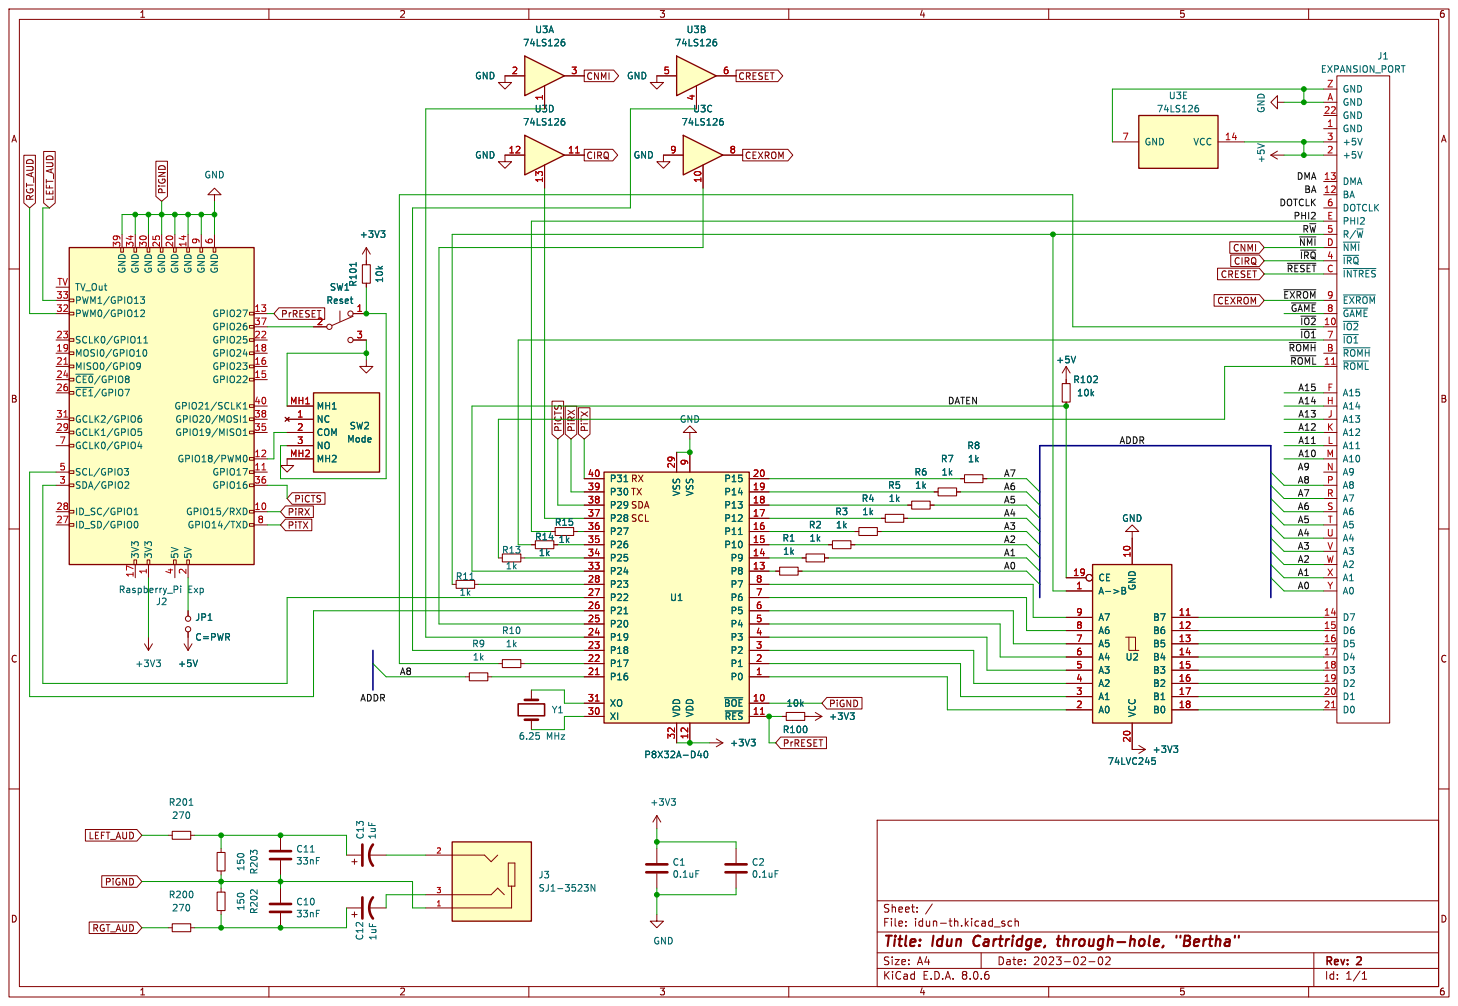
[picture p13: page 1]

J1 EXPANSION_PORT
A0 Y GND Z
GND 22 +5V 3 ~{IRQ} 4 R/~{W} 5 DOTCLK 6 ~{IO1} 7 ~{GAME} 8 ~{EXROM} 9 GND A
GND 1 ~{IO2} 10 ~{ROML} 11 BA 12 DMA 13 D7 14 D6 15 D5 16 D4 17 D3 18 D2 19

PiGND PiCTS PiRX PiTX

File: idun-th.kicad_sch Sheet: / R100

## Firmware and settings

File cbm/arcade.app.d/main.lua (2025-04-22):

-- Constant
local util = require('idun-util')
local gamelist = require('gamelist')
local serpent = require('serpent')
local search = require('search')
local info = require('info')
local lfs = require('lfs')
local d64 = require('d64reader')
require ('iconv')

local m8
local gamedb, found, prglist = {}, {}, {}
local result_start, _ = 0, nil
local searchstr, select_gid, select_path, disk_image_path = "", "", "", ""

-- Helper function to split search string
local function splittokens(s)
    local res = {}
    for w in s:gmatch("%S+") do
        res[#res+1] = w
    end
    return res
end

-- Helper function to pad strings + nul char
local function pads(str, length)
    local pad = string.format('%-'..length..'s', str)
    if pad:len()>length then pad = string.sub(pad, 1, length) end
    return string.pack('c'..length..'b', pad, 0)
end

-- Helper function to get PRG names from P64 files
local function parse_p64(path, fname)
    local _, e = string.find(fname, "%.[Pp]0%d")
    if e ~= fname:len() then return false, nil end
    local file = io.open(path..'/'..fname, "rb")
    assert(file, "Failed opening P64 file: "..fname)
    local hdr = file:read(26)
    local s, _, prgname = string.find(hdr, "C64File%z([%w%p%s]+)%z")
    assert(s==1, "Failed parsing P64 file")
    return true, prgname
end

-- Parameter checking for m8 extensions
local function check_results_sz(msg)
    assert(msg:len()==1+10+21*23, "results() msg error")
end

local function check_inform_sz(msg)
    assert(msg:len()==140, "inform() msg error")
end

local function check_prglist_sz(msg)
    assert(msg:len()==9*17+2, "programs() msg error")
end

local function update_search_results(start, total, sz)
    local asc = ""
    if not sz then sz = math.min(#found-start+1, 21) end
    local msg = string.pack('b', sz)
    -- Append the overall results/count
    msg = msg .. string.format("%4d/%-5d", start, total)
    -- Append the search results
    for i = start, start+sz-1 do
        asc = pads(gamedb['alpha'][found[i]][1], 22)
        msg = msg .. util.asc2pet(asc)
    end
    -- Pad the unused rows with blank entries
    for i = sz+1, 21 do
        msg = msg .. pads(' ', 22)
    end
    m8.results(msg, check_results_sz)
    result_start = start
end

local function update_program_list()
    local disk = 0x00
    if disk_image_path ~= '' then
        disk = 0xff
    end
    local sz = math.min(#prglist, 9)
    -- First byte is TRUE when it's a D64 image
    local msg = string.pack('BB', disk, sz)
    for i = 1, sz do
        msg = msg .. pads(prglist[i], 16)
    end
    -- Pad the unused rows with blank entries
    for i = sz+1, 9 do
        msg = msg .. pads(' ', 16)
    end
    m8.programs(msg, check_prglist_sz)
end

local function clearsearch(n)
    -- Set found to first 21 gamelist entries
    found = {}
    for i = n,n+20 do
        found[i] = i
    end
    update_search_results(n, #gamedb['alpha'], 21)
end

-- Event handlers
function Ev_key_search(c)
    if c == 0x14 then   -- Backspace
        if searchstr:len() > 1 then
            searchstr = string.sub(searchstr, 1, -2)
        else
            searchstr = ''
            clearsearch(1)
            return
        end
    else
        local ch = string.char(c)
        searchstr = searchstr..ch
    end

    local terms = util.pet2asc(searchstr)
    found = search.get(terms)
    if #found>0 then update_search_results(1, #found) else clearsearch(1) end
end

function Ev_key_hotkey(c)
    if c == 0x16 or c == 0x17 then
        if c == 0x16 then
            -- previous page
            result_start = math.max(result_start-21, 1)
        else
            -- next page
            result_start = result_start+21
        end

        if result_start <= #found then
            update_search_results(result_start, #found)
        else
            clearsearch(result_start)
        end
        return
    end
    if c == 0x0d then
        prglist = {}
        disk_image_path = ''
        for file in lfs.dir(select_path) do
            local ufile = string.upper(file)
            if string.sub(ufile, -4) == ".D64" then
                -- list only PRG files
                local dirlist = d64.directory(select_path..file, 0x82)
                for _, v in pairs(dirlist) do
                    table.insert(prglist, v.name)
                end
                disk_image_path = ':'..select_path..file
                break
            elseif string.sub(ufile, -4) == ".PRG" then
                table.insert(prglist, util.asc2pet(file))
            else
                local p00, prgname = parse_p64(select_path, file)
                if p00 then table.insert(prglist, prgname) end
            end
        end
        update_program_list()
    end
    if c == 0x85 then   --F1 key
        -- Show Recents
        local r = gamelist.recents()
        if not r or #r==0 then
            clearsearch(1)
        else
            found = {}
            for i = 1,#r do
                found[i] = gamedb['byid'][r[i]]
            end
            update_search_results(1, #found)
        end
    end
    if c == 0x86 then   --F3 key
        -- Show Favorites
        local f = gamelist.favorites()
        if not f or #f==0 then
            clearsearch(1)
        else
            found = {}
            for i = 1,#f do
                found[i] = gamedb['byid'][f[i]]
            end
            update_search_results(1, #found)
        end
    end
    if c == 0x88 then   --F7 key
        gamelist.favorite(select_gid)
    end
end

function Ev_select_results(s)
    s = s + result_start - 1
    assert(found[s], string.format("No result selected by %d",s))
    select_gid = gamedb['alpha'][found[s]][3]
    select_path = string.toutf8(gamedb['alpha'][found[s]][2])
    local i = info.get(select_path)
    local inf = string.format("%4d", s)
    if i['Published'] then
        inf = inf..util.asc2pet(pads(i['Published'], 16))
    else
        inf = inf..util.asc2pet(pads("   (Unknown)", 16))
    end
    local bylines = 3
    if i['Developer'] then
        inf = inf..util.asc2pet(pads(i['Developer'], 16))
        bylines = bylines-1
    end
    if i['Coding'] then
        inf = inf..util.asc2pet(pads(i['Coding'], 16))
        bylines = bylines-1
    end
    if i['Graphics'] then
        inf = inf..util.asc2pet(pads(i['Graphics'], 16))
        bylines = bylines-1
    end
    if i['Music'] and bylines>0 then
        inf = inf..util.asc2pet(pads(i['Music'], 16))
        bylines = bylines-1
    end
    while bylines > 0 do
        inf = inf..pads(' ', 16)
        bylines = bylines-1
    end
    if i['Language'] then
        inf = inf..util.asc2pet(pads("in "..i['Language'], 16))
    else
        inf = inf..util.asc2pet(pads("in (Unknown)", 16))
    end
    if i['Genre'] then
        inf = inf..util.asc2pet(pads(i['Genre'], 16))
    else
        inf = inf..pads(' ', 16)
    end
    if i['Players'] and i['Control'] then
        local ctl = pads(i['Players'].."  "..i['Control'], 16)
        inf = inf..util.asc2pet(ctl)
    else
        inf = inf..pads(' ', 16)
    end
    if i['Trainers'] then
        inf = inf..util.asc2pet(pads("Trainers:"..i['Trainers'], 16))
    else
        inf = inf..util.asc2pet(pads("Trainers:0", 16))
    end
    m8.inform(inf, check_inform_sz)
end

function Ev_select_gamefiles(s)
    local i = tonumber(s)
    local path = select_path
    if disk_image_path ~= '' then
        path = disk_image_path
    end
    local msg = string.pack("zz", util.asc2pet(path), prglist[i])
    -- Add to recents list
    gamelist.recent(select_gid)
    m8.launch(msg)
end

-- Only import these after defining Event handlers
m8 = require('m8api')
require('m8x')

local function load_game_data()
    local fidx, _ = io.open('gamelist.idx')
    local db
    if not fidx then
        io.write("Generating index...")
        db = gamelist.load()
        fidx, _ = io.open('gamelist.idx', 'w')
        assert(fidx, "Error creating game index")
        fidx:write(serpent.dump(db))
        fidx:close()
    else
        local ok
        local dumpstr = fidx:read('*a')
        ok, db = serpent.load(dumpstr)
        assert(ok, "Error loading game index")
    end
    return db
end

m8.VERBOSE = false
-- Load the gamelist
sys.chdir("g:")
gamedb = load_game_data()
search.setdb(gamedb)

-- Main application initialize
clearsearch(1)

-- Main application loop
while true do
    local type, id, p = m8.waitevent()
    if type then
        assert(type <= #m8.EVENT, "Invalid event type:"..type)
        local ev = m8.EVENT[type]
        assert(id <= #ev, "Invalid event id:"..id)
        ev[id](p)
    end
end

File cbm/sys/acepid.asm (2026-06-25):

; Idun Kernel, Copyright ©2023 Brian Holdsworth
; This is free software, released under the MIT License.

; Uses `fileinfoTable` defined as 256-byte table in idunk. 
; 8 bytes per Fcb #0-31 as `CXXYYMMO`
;
; C  = pid device channel (#31 is reserved for memory-mapped files)
; XX = bytes remaining for read w/ virtual disk files
;      -or- current seek position w/ memory-mapped files
; YY = total length of file
; MM = far mem page address (only w/ mmap files)
; O  = mode flag with which file was opened

; local var used for temporary storage of `zw` system var
; values passed in `zw` should not modify it!
zz !byte 0,0

BlockLfn = 30          ; fixed Lfn for block read/write
CommandLfn = 31        ; fixed Lfn for commands

getFileinfoChan = * ;(.X=fcb) : .A=device
  txa
  asl
  asl
  asl
  tax
  lda fileinfoTable,x
  rts

setFileinfoChan = * ;(.A=device, .X=fcb, openMode) : .A=device
  pha
  pha
  txa
  asl
  asl
  asl
  tax
  pla
  sta fileinfoTable,x
  ; init bytes to $FFFF as a flag to indicate
  ; size is not yet known.
  lda #$ff
  inx
  sta fileinfoTable,x
  inx
  sta fileinfoTable,x
  inx
  inx
  inx
  inx
  inx
  lda openMode
  sta fileinfoTable,x
  pla
  rts

getFileinfoMode = * ;(.X=fcb) : .A=mode
  inx
  txa
  asl
  asl
  asl
  tax
  dex
  lda fileinfoTable,x
  rts

!macro getFileinfoLength {
  pha
  txa
  asl
  asl
  asl
  clc
  adc #1
  tax
  lda fileinfoTable,x
  sta zz
  inx
  lda fileinfoTable,x
  sta zz+1
  pla
}
; This gets and sets both the length and the remaining bytes.
setFileinfoLength = * ;(.X=fcb) : zz=16-bit file length
  txa
  pha
  ; TALK
  jsr getFileinfoChan
  jsr talkChan
  jsr pidChOut
  ; SECOND logical filenum
  pla
  tax
  jsr pidGetlfn
  ora #$60
  jsr pidChOut
  ; recv length (LSB, MSB)
- jsr pidChIn
  bcs -
  sta zz
- jsr pidChIn
  bcs -
  sta zz+1
  txa
  asl
  asl
  asl
  clc
  adc #1
  tax
  lda zz
  sta fileinfoTable,x
  inx
  inx
  sta fileinfoTable,x
  lda zz+1
  dex
  sta fileinfoTable,x
  inx
  inx
  sta fileinfoTable,x
  jsr pidDoUntalk
  rts

updateFileinfoBytes = *
  txa
  asl
  asl
  asl
  clc
  adc #1
  tax
  lda fileinfoTable,x
  sec
  sbc zz
  sta fileinfoTable,x
  inx
  lda fileinfoTable,x
  sbc zz+1
  sta fileinfoTable,x
  bne +
  dex
  ora fileinfoTable,x
  bne +
  lda #$ff
  ldx readFcb
  sta eoftable,x
+ rts

!macro closeFileinfo {
  pha
  tya
  pha
  txa
  asl
  asl
  asl
  tax
  lda #0
  ldy #8
- sta fileinfoTable,x
  inx
  dey
  cpy #0
  bne -
  pla
  tay
  pla
}

swap_count !byte 0
pidFdswap = *   ;( .X=Fcb1, .Y=Fcb2 )
  txa
  asl
  asl
  asl
  tax
  tya
  asl
  asl
  asl
  tay
  lda #8
  sta swap_count
- lda fileinfoTable,x
  pha
  lda fileinfoTable,y
  sta fileinfoTable,x
  pla
  sta fileinfoTable,y
  inx
  iny
  dec swap_count
  bne -
  clc
  rts

; Send UNLISTEN  and get error code
pidDoUnlisten = *
  jsr pidFlushbuf
  ; UNLISTEN
  lda #$3F
  jsr pidChOut
  ; Get errno
- jsr pidChIn
  bcs -
  sta errno
  cmp #0
  beq +
  cmp #aceAppFileOpen
  beq +
  sec
  rts
+ lda openFcb
  clc
  rts

;*** (.X=Fcb) : .A=Lfn
pidGetlfn = *
  txa
  and #$30
  beq +
  txa
  rts
+ lda lftable,x
  rts

;*** (openDevice, openFcb, openNameScan, openMode, (zp)=name)
;    : .A=Fcb , .CS=error, errno
pidOpen = *
  ; LISTEN channel
  lda openDevice
  lsr
  lsr
  ldx openFcb
  jsr setFileinfoChan
  jsr listenChan
  jsr pidChOut
  ; OPEN logical filenum
  ldx openFcb
  jsr pidGetlfn
  ora #$A0
  jsr pidChOut
  ; send name
  ldy openNameScan
- lda (zp),y
  cmp #0
  beq +
  jsr pidChOut
  iny
  jmp -
+ lda #","
  jsr pidChOut
  lda openMode
  jsr pidChOut
  lda #0
  jsr pidChOut
  jsr pidDoUnlisten
  bcc +
  rts
+ ldx openFcb
  lda openMode
  cmp #"p"
  bne +
  jsr setFileinfoLength
  jmp ++
+ cmp #"P"
  bne ++
  jsr setFileinfoLength
++lda openFcb
  clc
  rts

;*** (closeFd) : .CS=error, errno
pidClose = *
  ldx closeFd
  jsr getFileinfoChan
  bne +
  ; Fd is already CLOSEd
  rts
  ; LISTEN channel
+ jsr listenChan
  jsr pidChOut
  ; CLOSE logical filenum
  ldx closeFd
  jsr pidGetlfn
  ora #$80
  jsr pidChOut
  ldx closeFd
  +closeFileinfo
  jmp pidDoUnlisten
pidCloseall = *
  lda #$5f
  jsr pidChOut
  ldx #32
  stx closeFd
- dec closeFd
  bmi +
  jsr pidClose
  jmp -
+ rts

readlentemp = *
  !byte 0,0

;*** (readFcb, readPtr[readMaxLen]) : readPtr[zw], .AY=zw,
;                                               : .CS=error, .ZS=eof, errno
pidRead = *
  ; Check whether OPEN was binary mode
  ldx readFcb
  jsr getFileinfoMode
  cmp #"b"
  beq +
  cmp #"B"
  beq +
  lda #<pidReadseq
  ldy #>pidReadseq
  sta readGetbuf+1
  sty readGetbuf+2
  jmp ++
+ lda #<pidGetbuf
  ldy #>pidGetbuf
  sta readGetbuf+1
  sty readGetbuf+2
  ; TALK channel
++ldx readFcb
  jsr getFileinfoChan
  jsr talkChan
  jsr pidChOut
  ; SECOND logical filenum
  ldx readFcb
  jsr pidGetlfn
  ora #$60
  jsr pidChOut
  ; determine how much can be recv'd (readMaxLen >= zz)
  calcRecvLength = *
  ldx readFcb
  +getFileinfoLength
  lda zz+1
  sec
  sbc readMaxLen+1
  bcc ++
  beq +
  lda readMaxLen+0
  sta zz+0
  lda readMaxLen+1
  sta zz+1
  jmp ++
+ lda zz+0
  sec
  sbc readMaxLen+0
  bcc ++
  lda readMaxLen+0
  sta zz+0
  lda readMaxLen+1
  sta zz+1
  ; recv to buffer readPtr[zz]
  readLenSet = *
++lda zz+1
  sta readlentemp+1
  lda zz+0
  sta readlentemp+0
  ora zz+1
  bne +
  jmp readEnd  ; end if zz==0
  readMore = *
+ ldx #0
  cpx zz+1
  bmi readPage
  beq readLast
  jmp readEnd
  readPage = *
  jsr readGetbuf
  bcc +
  jmp pidDetectEOF
+ inc readPtr+1
  dec zz+1
  bne +
  lda zz+0
  beq readEnd
+ jsr pidDoUntalk
  ; TALK for next page
  ldx readFcb
  jsr getFileinfoChan
  jsr talkChan
  jsr pidChOut
  ; SECOND logical filenum
  ldx readFcb
  jsr pidGetlfn
  ora #$60
  jsr pidChOut
  jmp readMore
  readLast = *
  ldx zz+0
  ;WARNING passing zero to readGetbuf reads #256 bytes!
  beq readEnd
  jsr readGetbuf
  bcc readEnd
  pidDetectEOF = *
  sty zz
  jsr pidFlushbuf
  ldx readFcb
  lda #$ff
  sta eoftable,x
  jmp pidDoUntalk
  readEnd = *
  ; subtract length from remaining
  lda readlentemp
  sta zz
  lda readlentemp+1
  sta zz+1
  ldx readFcb
  jsr updateFileinfoBytes
  pidDoUntalk = *
  lda #$5F
  jsr pidChOut
  ldy zz+1
  lda zz
  clc
  rts
readGetbuf = *
  jmp pidReadseq
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

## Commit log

2023-04-10 Describe reset button and JP1 in README.
2023-04-17 FIX: tty escape code handling to better support frotz
    [tty.asm]
2023-04-27 FIX: additional tty escape code handling; now works with Bureaucracy "Software License Form" on frotz.
    [tty.asm]
2023-05-15 FIX: shortcut NMI RESTORE key checking when it's memmapper causing the interrupt.
    [ace.asm, toolbox.asm]
2023-06-02 FIX: two bugs in BASIC booter
    [browse.asm, hook.asm]
2023-08-11 FIX: timing issue with MOS 8564R5
    [ace.asm, hook.asm]
2023-09-16 FIX: new default values for some VDC registers in PAL mode; values taken from latest rev of CBM kernal
    [acevdc.asm]
2023-11-21 FIX: `zload` cmd works on real hardware; needed 1MHz mode switching
2023-11-22 FIX: Check size of z80 binary and proper screen restore for 40-columns mode.
    [acevic.asm]
2023-12-03 FIX: hello.app freezing on exit. Socket should be closed first.
    [app.asm]
2023-12-11 FIX: VDC mode 5/6 issues
    [mode.asm]
2024-01-03 FIX: booter so it works with or without patched ROM
    [hook.asm]
2024-01-03 FIX: Bug preventing C64 mode BASIC working
    [hook.asm]
2024-01-20 FIX: key repeat for virtual keyboard
    [acepiserv.asm]
2024-01-24 FIX: Detect EOF while reading seq. files
    [acepid.asm, toolbox.asm]
2024-01-26 Switched to using Lfn instead of Fcb to identify open files on RPi side.
2024-01-27 FIX: lua sample apps need to close the lua stream on exit.
    [app.asm]
2024-02-10 Added 3D printed case design files
    [case_bottom.stl, case_top.stl, reset_button.stl]
2024-02-21 Fix some code warnings with latest acme assembler
    [acecon.asm, hook.asm]
2024-02-22 Removed acme assembler code; use package install instead. Added acme_lib.
2024-02-26 FIX: File write bug
    [acepid.asm, edit.asm]
2024-02-28 FIX: Handle viewport scroll ESC sequences in `tty`.
    [tty.asm]
2024-03-01 Added sys/stdlib.asm and reworked the file write bug
    [acecon.asm, acepid.asm]
2024-03-05 FIX: detect loading invalid binary
    [acemem.asm]
2024-04-03 Added Interactive BOM file (HTML format)
2024-05-14 WIP: Fixes to the koala viewer
    [ace.asm, acemem.asm, acevic.asm]
2024-05-15 Rename showvic.app->koala.app, fix path search for .app files,
    [ace.asm, acemem.asm, acepid.asm]
2024-05-16 FIX: Return to same text mode we started from
    [acevic.asm]
2024-05-22 Added samples/plasma.asm and Cmd+J hotkey for switching screen modes.
2024-05-25 Update plasma sample app; use Lua to calculate the pattern
2024-07-27 Replaced aceFileInfo call with aceFileStat.
    [ace.asm, acecall.asm, acepid.asm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]
2024-09-14 Modify disk image mounts from BASIC to have R/W access
2024-09-14 FIX: joystick input for toolbox menus (uses control port 2)
    [ace.asm, toolbox.asm]
2024-09-15 FIX: move toolbox vars back to zero-page
    [ace.asm, toolbox.asm]
2024-09-24 FIX: Rollback a change that broke `zload`
    [acepid.asm]
2024-10-01 FIX: for undefined symbol in sample apps
    [app.asm]
2024-10-25 FIX: update ROM patch; also 'arcade,app' and 'browse' mount disk images as R/W
    [browse.asm]
2024-10-26 FIX: 'go64' to mount disk images in R/W mode
2024-12-18 FIX: `boot-64` program not working w/o patched C64 kernal ROM
    [hook.asm]
2025-02-20 Update schematic- show connection to IO2 replacing A9.
2025-02-20 Update acepiserv to work correctly with re-factored Mapper
    [acepiserv.asm]
2025-02-20 Update for new ROML soft-switch handling
2025-02-20 Update ROM patch; NMI handler using new soft-switches
2025-02-21 FIX: don't hard code default shell app
    [acecon.asm, acemem.asm, acetag.asm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]
2025-03-09 FIX: eram test for C128/2MHz
    [eram.asm]
2025-03-15 Integrate ERAM support and API changes (with bugs!)
    [ace.asm, acecall.asm, acecon.asm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]
2025-03-15 Bug fixes for ERAM; mostly in mmap implementation
    [acemem.asm, eram.asm, tags.asm]
2025-03-17 Bug fixes for mmap following reset and restart.
    [ace.asm, acemem.asm, config.asm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]
2025-03-17 Add eram.md doc file and fix TPA size for C64 when ERAM is not available.
    [config.asm]
2025-03-21 Fix GC for tagged memory blocks, aceFileStat bug, and memory reclaim.
    [acecall.asm, acemem.asm, config.asm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]
2025-03-23 Modify dos shell exit procedure to preserve device settings.
2025-03-24 Improve `.app` file loads; no longer have to include the extension in load request.
    [acemem.asm, acepid.asm]
2025-03-25 Easily send IEC device commands from BASIC using `@#n` to select device, then `@<command>` to send a command.
2025-03-27 FIX: need to disable toolbox irq when loading an app
    [acepid.asm]
2025-03-27 FIX: `joys` command not very responsive
    [joys.asm]
2025-03-28 Update makerom script; use `/8` switch to make a U4 ROM for C64
2025-04-05 FIX: `cpm.app` stack frame
    [acecall.asm, acepid.asm]
2025-04-06 FIX: ensure 2MHz mode OFF when switching to z80
2025-04-16 WIP: Improve `mount` cmd (Issue #16)
    [ace.asm, acecall.asm, acepid.asm]
2025-04-19 WIP: Issue #15; added `aceDirAssign` API for mounting directory
    [ace.asm, acecall.asm]
2025-04-19 Added `assign` command; similar to `mount`, but for assigning directory to a drive. This is the eventual solution to Issue #16.
2025-04-21 Added support for "@" IEC device commands from idun-shell. Also add drive switching with just "a:", "c:", etc.
2025-04-25 Minor fix to `tty` for ESC J handler; fixes WordStar screen redraw.
    [tty.asm]
2025-04-27 FIX: chrset-standard working for soft-80 display driver
2025-08-30 FIX: VDC on PAL machine; Display is unstable #27
    [acevdc.asm]
2025-09-07 FIX: `basic` command launches Basic 7.80, but it crashes, on C128 (#29)
    [ace.asm]
2025-09-07 FIX: launching Idun tool from floppy fails header check
    [acemem.asm]
2025-09-07 FIX: broken floppy drive status checking causes `del` cmd to fail
    [acecall.asm]
2025-09-10 FIX: `copy` cmd for moving files between two virtual drives
    [acecall.asm]
2025-10-12 WIP: shell.app drives command; mount/assign virtual devices
2025-10-16 WIP: keyboard switching (Com+k) in `shell.app`
2025-10-24 FIX: Keyboard switcher when used from shell.app
    [acecon.asm, tty.asm]
2025-10-24 Cleanup keyboard switching code
2025-10-24 Update some comments in soft-80 driver
2025-10-24 WIP: minor fixes to toolx/gfx; re-factor for toolx/pointer
    [koala.asm]
2025-10-24 FIX: `mousetest` fill on VIC-II, `tty` soft-80 mode, `tunnel` vibe
    [tty.asm]
2025-10-24 Fixes for `mandelbrot.app` plus remove some of the Vice emu checks since more functionality is supported in the latest Vice patch.
    [acemem.asm, app.asm]
2025-10-24 Fixes for `arcade.app`; cannot hard-code VIC-II screen base addr
    [app.asm]
2025-10-24 FIX: xVicGrOp drawing beyond screen memory
    [app.asm]
2025-10-24 FIX: xRectangle drawing; various bugs
    [toolbox.asm]
2025-10-24 Fix a couple merge issues
    [acecall.asm, acemem.asm]
2025-10-26 Fix some issues with merging `shell.app` with VIC-II changes
    [ace.asm, tty.asm]
2025-10-27 Fixes for `cube.app` on all video displays
    [app.asm]
2025-11-17 FIX: mmap for a child process should allocate from the next free ERAM block
    [acemem.asm]
2025-11-18 Issue #31; BASIC "go64" command now switches C128 to C64 mode with cartridge active.
    [hook.asm]
2025-11-23 FIX: showkoa bug working with Soft80; also arcade.app check for 40-col display.
    [ace.asm, acevic.asm, acewin.asm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]
2025-12-20 FIX: mmap for file spanning multiple eram blocks; was crashing garbage collection
    [eram.asm]
2025-12-24 FIX: mmap memory allocation for large files not properly tracked.
    [acemem.asm, eram.asm]
2025-12-27 WIP: Fixes for `diskcopy` (Issue #26)
    [diskcopy.asm, edit.asm]
2025-12-29 FIX: C128 kernel startup bug
    [ace.asm]
2026-01-08 FIX: aceWInCls boundary bug
    [acewin.asm]
2026-01-10 WIP: scrolling fix for tty
    [tty.asm]
2026-01-18 FIX: scrolling and cursor movement in tty
    [tty.asm]
2026-01-20 FIX: `drives` command intermittent crash
    [acecall.asm]
2026-01-25 FIX: `diskcopy` not detecting floppy; Prevent Z: drive from being the current drive at kernel start
    [ace.asm, diskcopy.asm]
2026-01-25 FIX: `diskcopy` virtual floppy addressing
    [diskcopy.asm]
2026-01-28 FIX: VIC-II display for `browse`; needs to use 40-col character set
    [browse.asm]
2026-02-01 FIX: 1. lockup when Lfn>29 2. sys.shell() should work in mlua REPL 2. floppy disk dir/catalog 3. dir bug in shell.app
    [acecall.asm, tty.asm]
2026-02-22 FIX: terminal output flush in shell.app
    [tty.asm]
2026-03-16 Fix: exit cleanly when Kvm disabled
    [tty.asm]
2026-03-20 FIX: advance to next line in terminal after Commodore command or Kvm switcheroo.
    [tty.asm]
2026-03-23 FIX: `showvdc` should check for C128/VDC machine
    [showvdc.asm]
2026-03-24 Working implementation for Commodore mouse with Kvm; needed to switch to relative mouse movements.
2026-04-03 Rework sidplay as a "usr" module.
    [acepiserv.asm, sidplay.asm]
2026-04-03 FIX: sidplay buffer copies
    [sidplay.asm]
2026-04-05 FIX: scale back `turbo` command; controlling C64u turbo does not work the way I hoped.
    [ace.asm]
2026-04-06 FIX: avoid c128 kernel boot issues caused by system IRQ handler over-writing data in $1200-$1300
    [hook.asm]
2026-04-09 Updates to Lua and API docs; also fix `usrcall` to match description in doc.
    [acepiserv.asm, eram.asm, sidplay.asm]
2026-04-15 FIX: `mode` cmd not loading soft80 characters
    [mode.asm]
2026-04-18 FIX: starting kernel with `@:` as the current device
    [ace.asm]
2026-05-17 FIX: `sidplay.lua` to not use assert(); return error code instead.
    [acepiserv.asm]
2026-05-19 FIX: Timing around UNLISTEN command; could result in lockup when using fast Turbo modes.
    [acecall.asm, acepid.asm]
2026-05-23 Map Backarrow key to Escape in `tty` for C64; also fixed bug with the compose/hex input feature.
    [keys.asm, tty.asm]
2026-06-12 Various fixes for `tty` to improve Mystic BBS (and ANSI in general) compatibility.
    [tty.asm]
2026-06-16 FIX: disable C64U turbo before launching native program loader.
    [ace.asm]
2026-07-16 cmdchClose changed to expect device instead of fd all calls changed to pass device (only one was passing fd)
2026-09-13 kernMiscDeviceInfo, kernDirChange, kernDirRead, kernFileBload device type optimizations
2026-10-09 Removed jmpMio macro usage - not actually needed if we always have a machine i/o driver compiled in; Transitioned kernFileRemove and kernFileRename to use pid (#4/#7) as fallback. Replaced renameScan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
    [acecall.asm]
2026-10-09 getDiskDevice bails out of caller on non-disk devices as it is called only for disk-based functions
2026-10-09 Saving some buttons on errno returning code
2026-10-09 Optimized kernFileClose device type selection path
2026-10-09 Read device type ordering normalized, returning illegal device for #6 (which should use tty api)
2026-10-09 kernFileWrite refactoring, returning invalid device for #5 and #6 i Please enter the commit message for your changes. Lines starting

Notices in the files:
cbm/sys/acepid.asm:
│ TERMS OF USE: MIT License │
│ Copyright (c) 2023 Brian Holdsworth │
